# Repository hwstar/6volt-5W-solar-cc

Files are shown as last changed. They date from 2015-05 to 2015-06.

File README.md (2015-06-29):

***6volt-5W-solar-cc***
=============

This is a solar charge controller for use with 5 watt 6 volt solar panels.

**Introduction**

The project use a custom printed circuit board for the charge controller
power management electronics, and requires an external Arduino pro mini
to run the control firmware.

Setup in the lab:

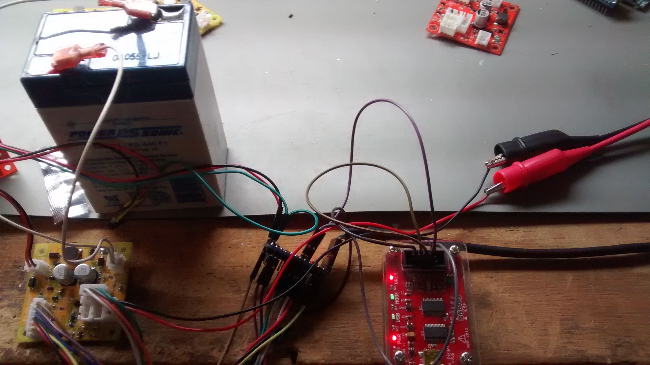
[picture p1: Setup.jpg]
ProjectSetup


The power management board design has the following features:

* PV input transient and reverse polarity protection
* Sensing for PV input voltage, converter output current, load current,
and battery voltage.
* PV Back feed protection using a dedicated MOSFET.
* PTC and reverse polarity protection on the battery connector.
* 3 sets of 3 pin connectors for loads. 
* 4 pin sense connector for current and voltage sensing to the Arduino
* 6 pin control connector for control signals from the Arduino
* Dedicated MOSFET for load switching.
* Switched and unswitched load configuration using solder jumpers.
* Double sided circuit board 5cm X 5cm

Front view of board:

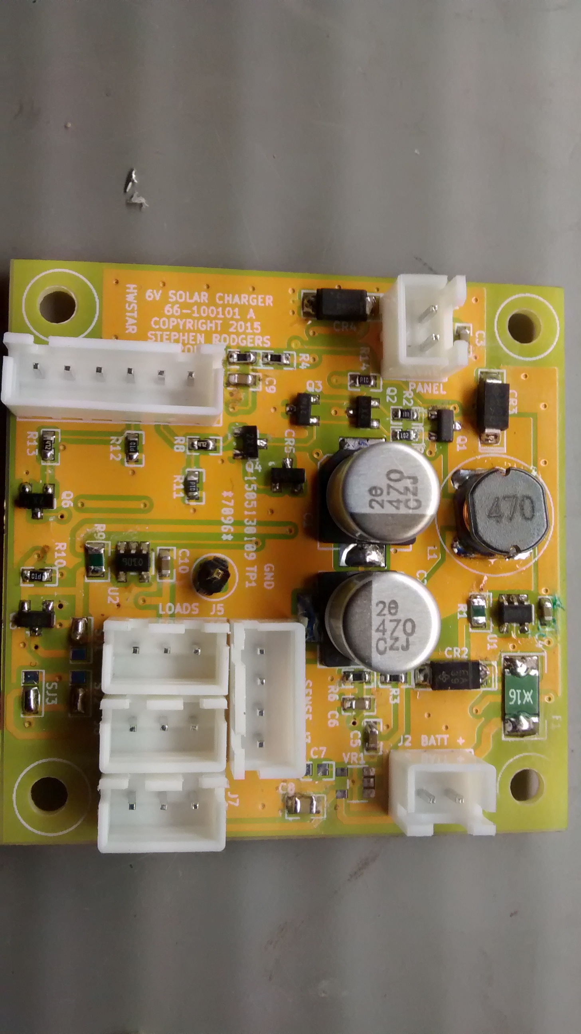
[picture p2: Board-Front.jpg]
BoardFront


Rear view of board:

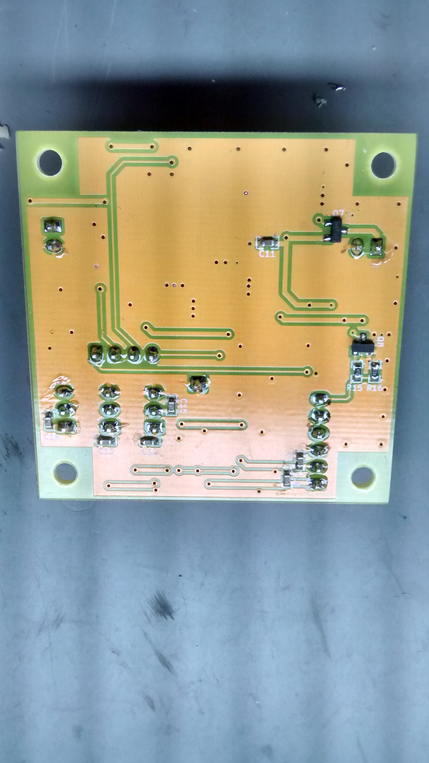
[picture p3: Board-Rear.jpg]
BoardRear


**Board Blanks**

Board blanks are available on Tindie:

https://www.tindie.com/products/hwstarsr/6-volt-5-watt-solar-charge-controller

**Firmware**

The firmware is hosted as a separate project on my github pages.
See [fw-6volt-5W-solar-cc](https://github.com/hwstar/fw-6volt-5W-solar-cc). For more details on
the firmware features, please visit the firmware page.

**Python/tkinter utility**

A Python/tkinter utility is available to download variables from the
charge controller in real time using a Bus Pirate and an I2C interface.
This is also hosted on my github pages under 
[chargectrlr-python-buspirate](https://github.com/hwstar/chargectrlr-python-buspirate).

**License**

CC-BY-SA

**Disclaimer**

This project uses a lead acid battery. Please observe all safety 
precautions listed on the battery. Enclose this project in a metallic
fireproof enclosure. Keep internal temperatures within the operating
limits of the battery. Not responsible for life, or loss of property
under any circumstance!

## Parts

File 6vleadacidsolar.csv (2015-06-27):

Item | Part Number | Qty | Reference(s) | Title/Description | Value on Schematic | Manufacturer | Manufacturer Part Number
1 | 800009-477 | 2 | C1,C2 | CAP,ELECT,8MM,470u,16V,LOW ESR | 470U | United Chemicon | EMZJ160ADA471MHA0G
2 | 800000-104 | 13 | C3-C6,C9-C15,C17,C18 | CAP,0603,0.1u,25V,X7R | 0.1U | Open Market | N/A
3 | 800002-471 | 1 | C7 | CAP,0603,470p,50V,C0G | 470p | Open Market | N/A
4 | 800003-106 | 1 | C8 | CAP,0805,10u,25V,X5R | 10U | Open Market | N/A
5 | 800109-101 | 2 | CR2,CR3 | DIODE, RECT,SHOTTKY,1A,50V,SMA | ES1A | Fairchild Semiconductor | ES1A
6 | 800132-013 | 1 | CR4 | DIODE,TVS,SMA,13V | 1SMA13AT3G | On Semiconductor | 1SMA13AT3G
7 | 800127-101 | 1 | CR5 | DIODE,SCHOTTKY,SGL,SOT-23 | BAT54 | Diodes Inc. | BAT54-7-F
8 | 800133-110 | 1 | F1 | FUSE,PTC,1812,1.1A,9V | 1.1A | Tyco Electronics | MINISMDC160F
9 | 800114-102 | 2 | J1,J2 | CONN,HDR,SHROUDED,2 CKT,5MM,XH SERIES | CONN2 | JST | B2B-XH-A
10 | 800114-104 | 1 | J3 | CONN,HDR,SHROUDED,4 CKT,5MM,XH SERIES | CONN4 | JST | B4B-XH-A
11 | 800114-106 | 1 | J4 | CONN,HDR,SHROUDED,6 CKT,5MM,XH SERIES | CONN6 | JST | B6B-XH-A
12 | 800114-103 | 3 | J5-J7 | CONN,HDR,SHROUDED,3 CKT,5MM,XH SERIES | CONN3 | JST | B3B-XH-A
13 | 800101-047 | 1 | L1 | IND,DRUM,UNSH,47UH,1.4A,SDE0805 SERIES | 47uH | Bourns | SDE0805A-470K
14 | 800134-101 | 3 | Q1,Q5,Q7 | XSTR,MOSFET,P-CH,SOT-23,30V,-7.6A | SI2369 | Vishay | SI2369DS-T1-E3
15 | 800110-101 | 4 | Q2,Q4,Q6,Q8 | XSTR,GP,NPN,40V,SOT23 | MMBT4401 | Fairchild Semiconductor | MMBT4401
16 | 800111-101 | 1 | Q3 | XSTR,GP,PNP,-40V,SOT23 | MMBT4403 | Fairchild Semiconductor | MMBT4403
17 | 800018-039 | 2 | R1,R9 | RES,0805,CUR SENSE,0.039 OHM,1%,1/2W | 0.039 | Susumu | KRL1220E-M-R039-F-T5
18 | 800010-104 | 5 | R10-R12,R14,R16 | RES,0603,100K OHM,5% | 100K | Open Market | N/A
19 | 800010-472 | 3 | R8,R13,R15 | RES,0603,4.7K OHM,5% | 4.7K | Open Market | N/A
20 | 800010-100 | 1 | R2 | RES,0603,10 OHM,5% | 10 | Open Market | N/A
21 | 800023-100 | 3 | R3,R6,R7 | RES,0603,10.0K OHM,1% | 10.0K | Open Market | N/A
22 | 800023-200 | 1 | R4 | RES,0603,20.0K OHM,1% | 20.0K | Open Market | N/A
23 | 800010-102 | 1 | R5 | RES,0603,1K OHM,5% | 1K | Open Market | N/A
24 | N/A | 3 | SJ1-SJ3 | Solder Jumper | GS3 | N/A | N/A
25 | 800122-101 | 2 | U1,U2 | IC,CURRENT SENSOR,100V/V,SOT23-5 | CS30CL | ST Microelectronics | CS30CL
26 | 800105-101 | 1 | VR1 | IC,VREG,5V,150MA,SOT23-5 | MIC5205 | Micrel | MIC5205YM5 TR

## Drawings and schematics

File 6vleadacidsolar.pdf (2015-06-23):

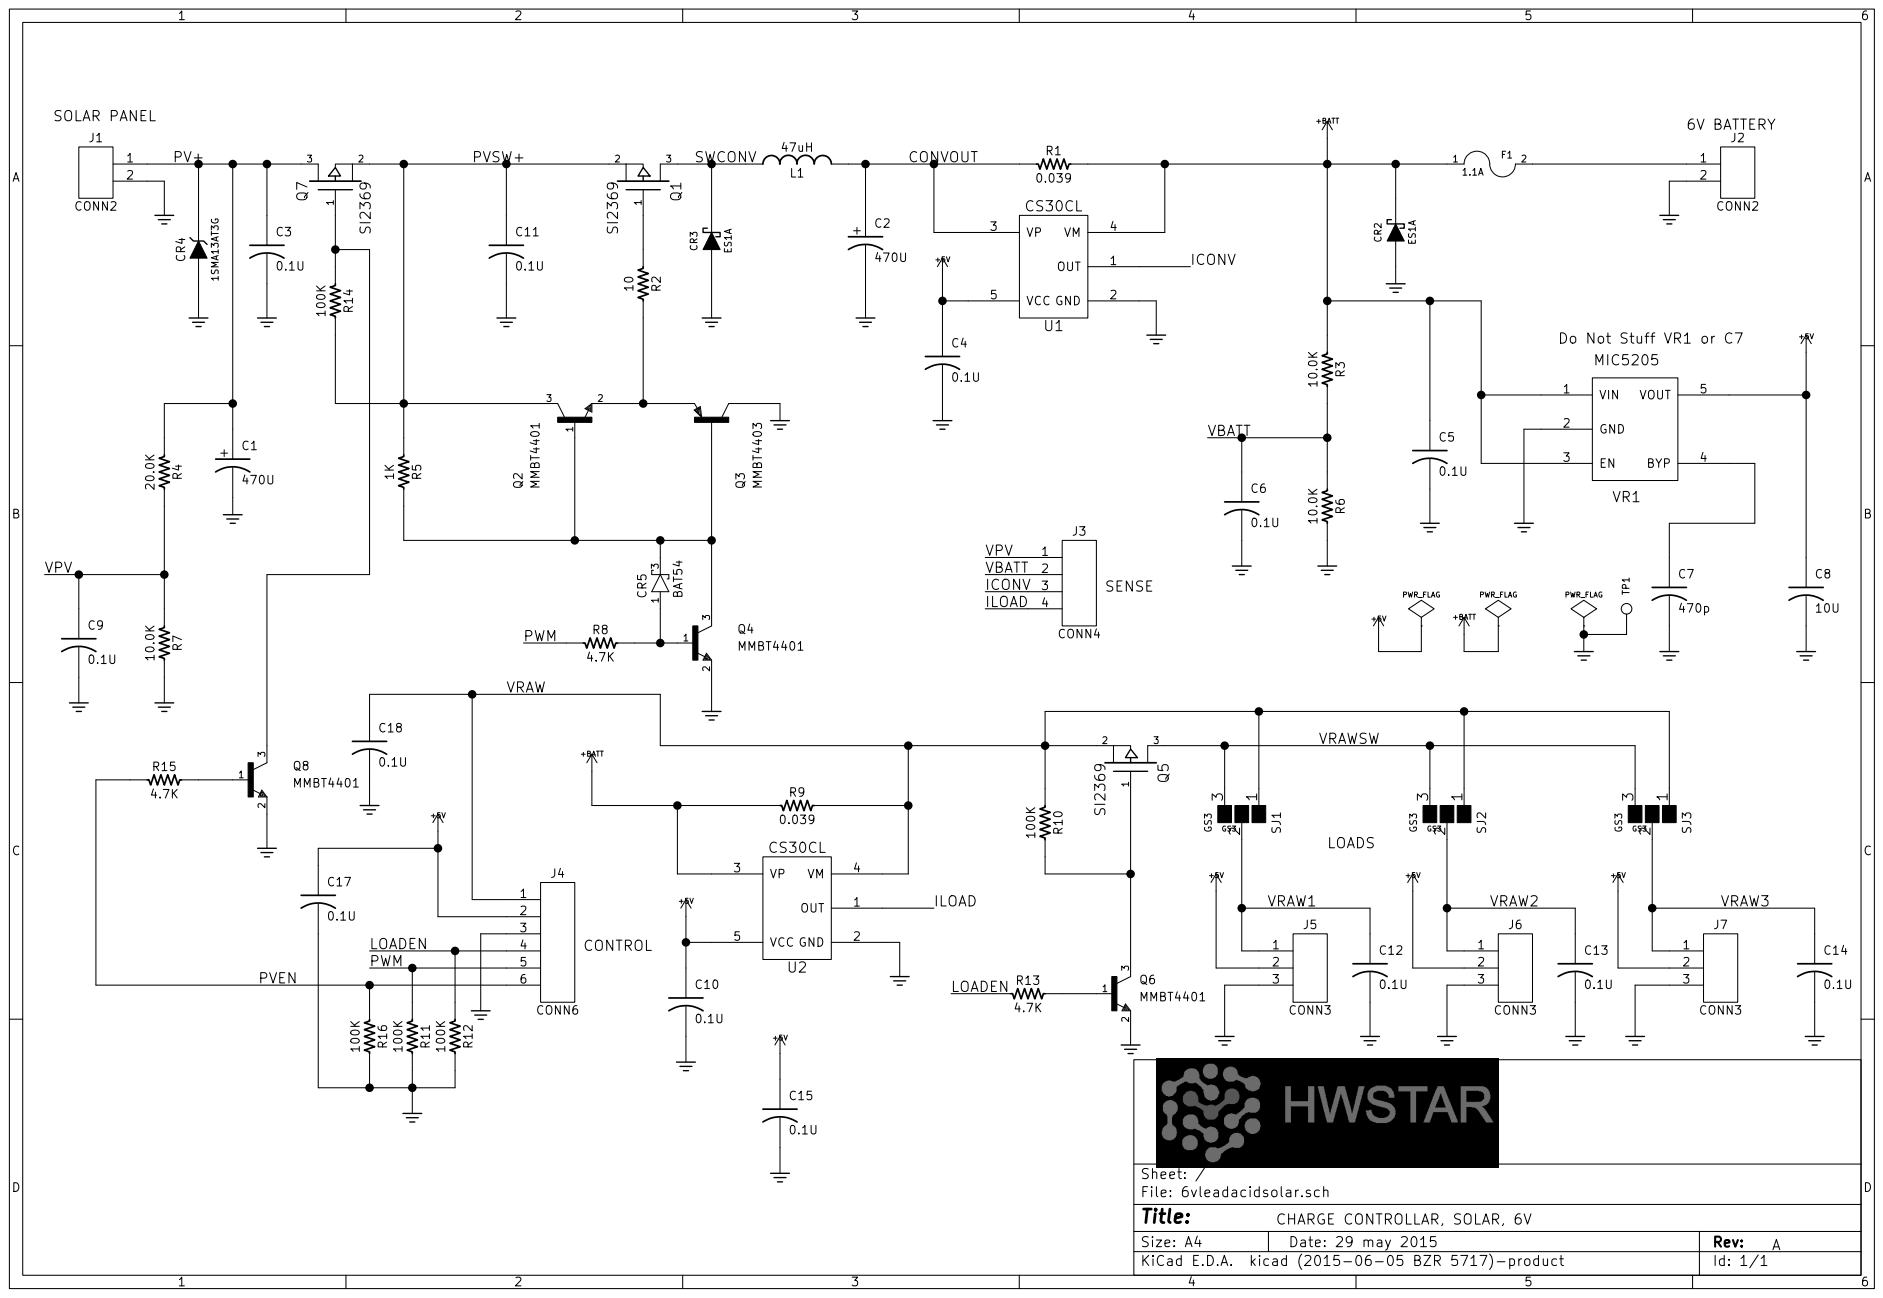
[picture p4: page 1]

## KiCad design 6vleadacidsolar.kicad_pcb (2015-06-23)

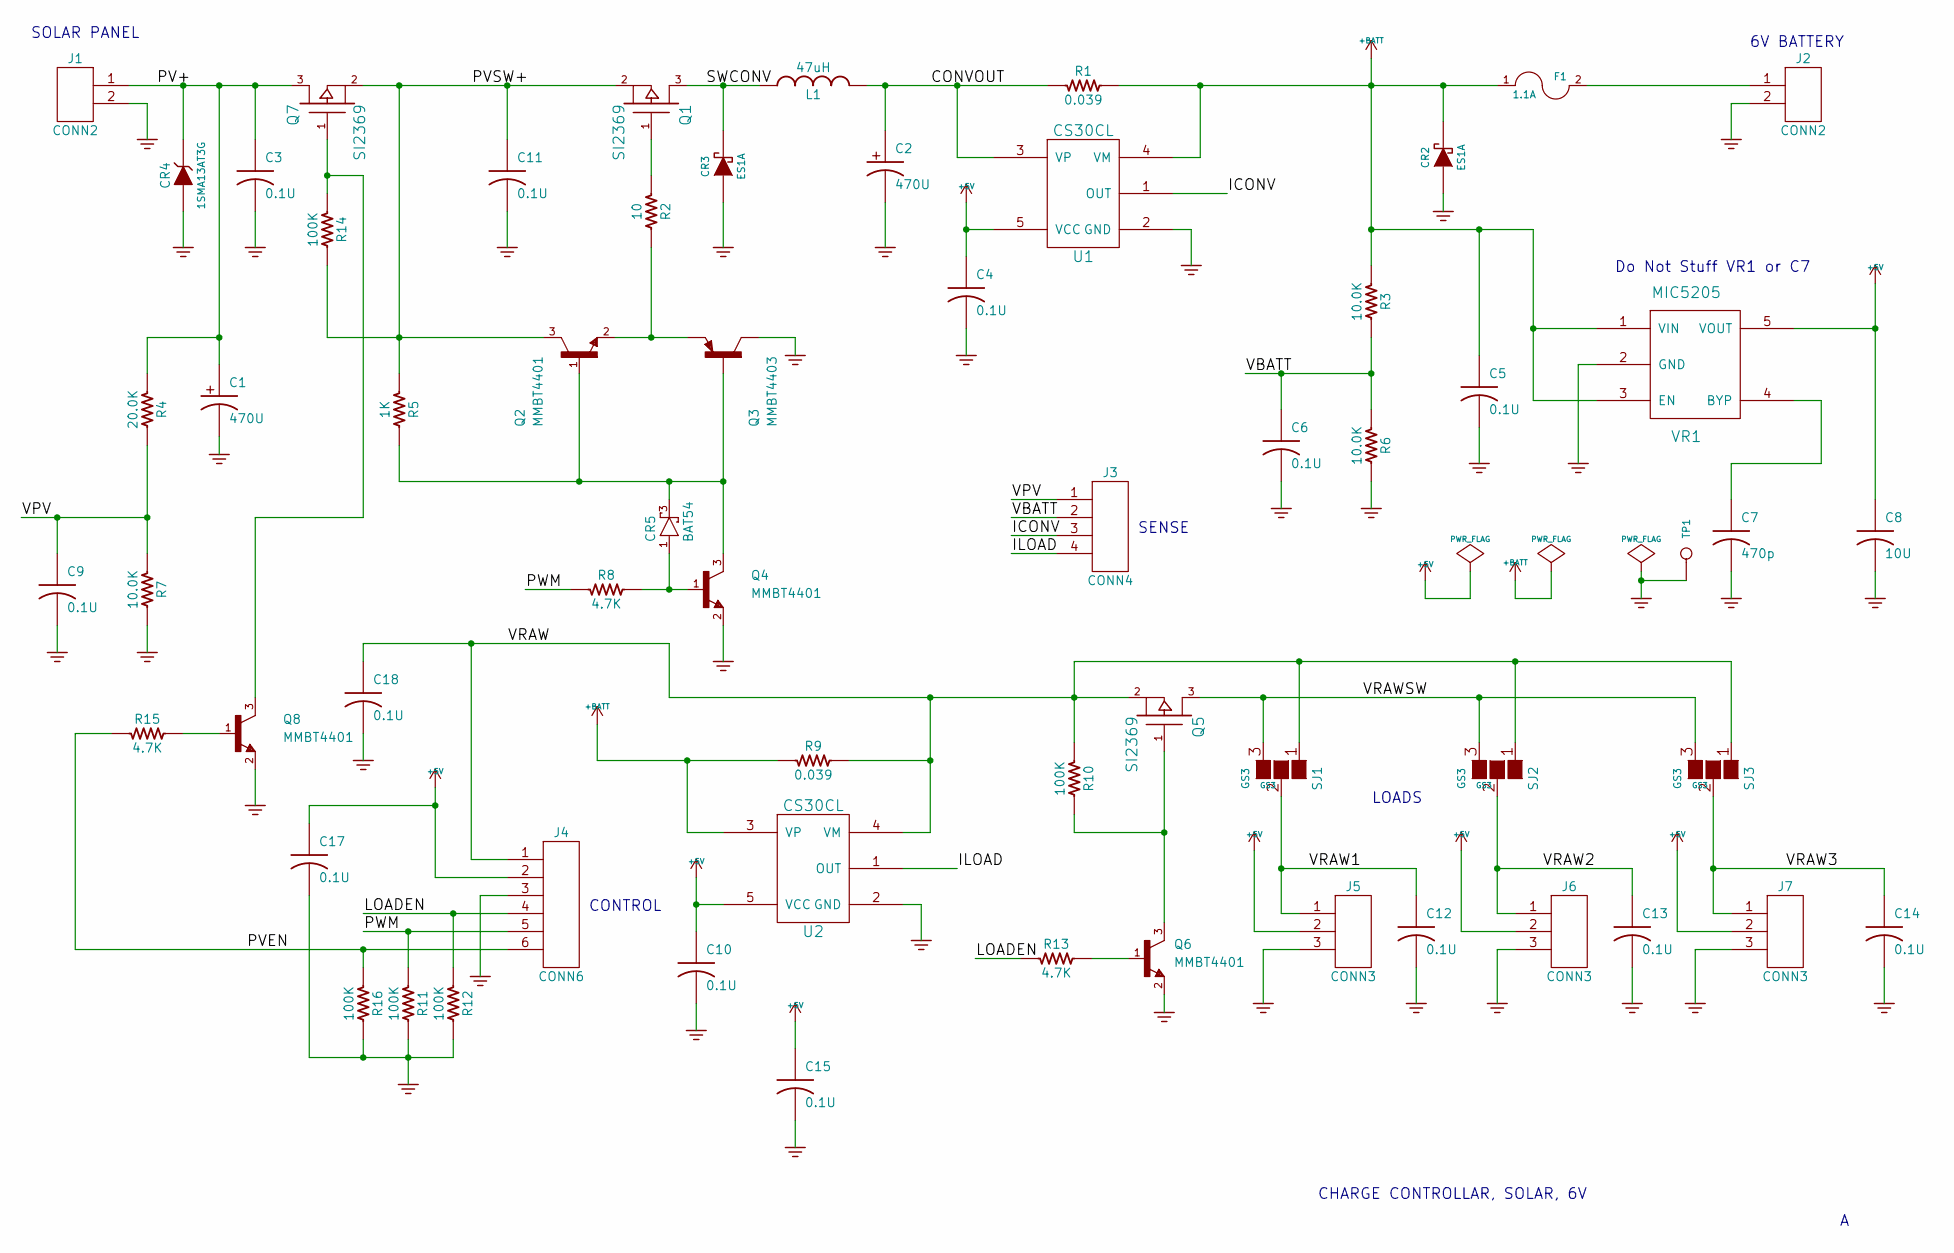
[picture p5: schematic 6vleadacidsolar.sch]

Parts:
C1, C2: 470U; PartNumber 800009-477
C3, C5, C6, C9, C10, C11, C12, C13, C14, C15, C17, C18: 0.1U; PartNumber 800000-104
C4: 0.1U
C7: 470p; PartNumber 800002-471
C8: 10U; PartNumber 800003-106
CR2, CR3: ES1A; PartNumber 800109-101
CR4: 1SMA13AT3G; PartNumber 800132-013
CR5: BAT54; SOT23; PartNumber 800127-101
F1: 1.1A; PartNumber 800133-110
J1, J2: CONN2; PartNumber 800114-102
J3: CONN4; PartNumber 800114-104
J4: CONN6; PartNumber 800114-106
J5, J6, J7: CONN3; PartNumber 800114-103
L1: 47uH; PartNumber 800101-047
Q1, Q5, Q7: SI2369; PartNumber 800134-101
Q2, Q4, Q6, Q8: MMBT4401; SOT23; PartNumber 800110-101
Q3: MMBT4403; custom-SOT23; PartNumber 800111-101
R1, R9: 0.039; PartNumber 800018-039
R2: 10; PartNumber 800010-100
R3, R6, R7: 10.0K; PartNumber 800023-100
R4: 20.0K; PartNumber 800023-200
R5: 1K; PartNumber 800010-102
R8, R13, R15: 4.7K; PartNumber 800010-472
R10, R11, R12, R14, R16: 100K; PartNumber 800010-104
SJ1, SJ2, SJ3: GS3
TP1: CONN_1
U1, U2: CS30CL; PartNumber 800122-101
VR1: MIC5205; SOT23-5; PartNumber 800105-101

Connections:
+5V: C4.1, C8.1, C10.1, C15.1, C17.1, J4.2, J5.2, J6.2, J7.2, U1.5 (VCC), U2.5 (VCC), VR1.5 (VOUT)
+BATT: C5.1, CR2.2 (K), F1.1, R1.2, R3.1, R9.1, U1.4 (VM), U2.3 (VP), VR1.1 (VIN), VR1.3 (EN)
/CONVOUT: C2.1, L1.2, R1.1, U1.3 (VP)
/ICONV: J3.3, U1.1 (OUT)
/ILOAD: J3.4, U2.1 (OUT)
/LOADEN: J4.4, R12.1, R13.1
/PV+: C1.1, C3.1, CR4.2 (K), J1.1, Q7.3 (D), R4.1
/PVEN: J4.6, R15.1, R16.1
/PVSW+: C11.1, Q1.2 (S), Q2.3 (C), Q7.2 (S), R5.1, R14.2
/PWM: J4.5, R8.1, R11.1
/SWCONV: CR3.2 (K), L1.1, Q1.3 (D)
/VBATT: C6.1, J3.2, R3.2, R6.1
/VPV: C9.1, J3.1, R4.2, R7.1
/VRAW: C18.1, J4.1, Q5.2 (S), R9.2, R10.1, SJ1.1 (G1), SJ2.1 (G1), SJ3.1 (G1), U2.4 (VM)
/VRAW1: C12.1, J5.1, SJ1.2 (G2)
/VRAW2: C13.1, J6.1, SJ2.2 (G2)
/VRAW3: C14.1, J7.1, SJ3.2 (G2)
/VRAWSW: Q5.3 (D), SJ1.3 (G3), SJ2.3 (G3), SJ3.3 (G3)
GND: C1.2, C2.2, C3.2, C4.2, C5.2, C6.2, C7.2, C8.2, C9.2, C10.2, C11.2, C12.2, C13.2, C14.2, C15.2, C17.2, C18.2, CR2.1 (A), CR3.1 (A), CR4.1 (A), J1.2, J2.2, J4.3, J5.3, J6.3, J7.3, Q3.3 (C), Q4.2 (E), Q6.2 (E), Q8.2 (E), R6.2, R7.2, R11.2, R12.2, R16.2, TP1.1, U1.2 (GND), U2.2 (GND), VR1.2 (GND)
unnamed: C7.1, VR1.4 (BYP)
unnamed: CR5.1 (A), Q4.1 (B), R8.2
unnamed: CR5.3 (C), Q2.1 (B), Q3.1 (B), Q4.3 (C), R5.2
unnamed: F1.2, J2.1
unnamed: Q1.1 (G), R2.1
unnamed: Q2.2 (E), Q3.2 (E), R2.2
unnamed: Q5.1 (G), Q6.3 (C), R10.2
unnamed: Q6.1 (B), R13.2
unnamed: Q7.1 (G), Q8.3 (C), R14.1
unnamed: Q8.1 (B), R15.2

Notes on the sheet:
6V BATTERY
SOLAR PANEL
CONTROL
SENSE
LOADS
CHARGE CONTROLLAR, SOLAR, 6V
Do Not Stuff VR1 or C7

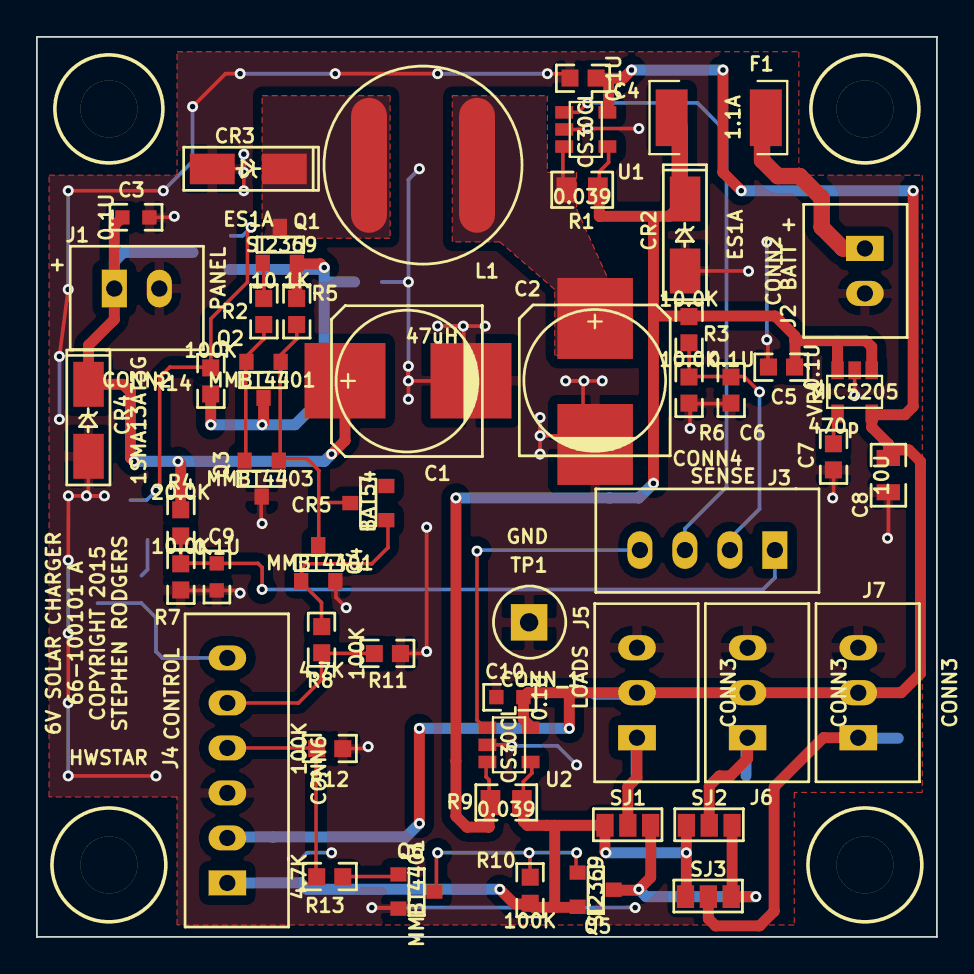
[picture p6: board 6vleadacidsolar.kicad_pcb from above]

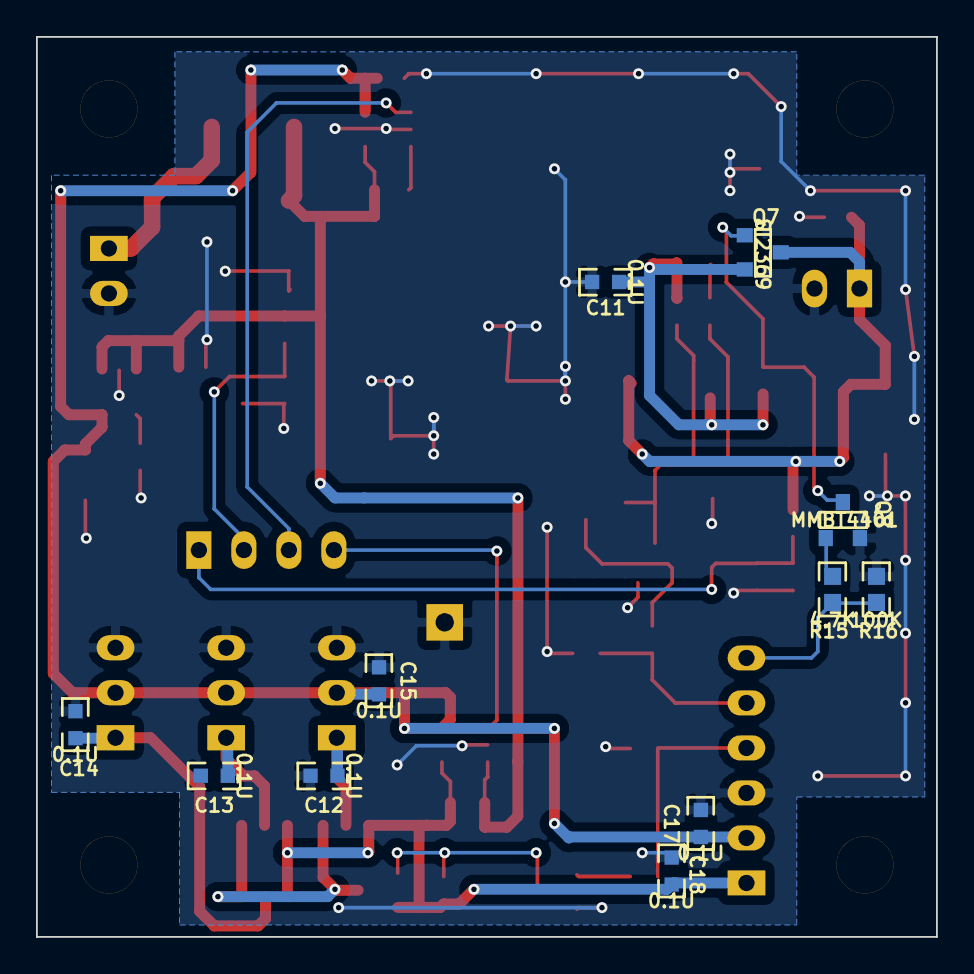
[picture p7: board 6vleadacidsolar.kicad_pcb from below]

Board: 2 copper layers, 50.0 x 50.0 mm, 65 parts (11 on the bottom side), 29 nets.

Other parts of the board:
MTGHOLE125, MTGHOLE125#2, MTGHOLE125#3, MTGHOLE125#4: VAL**; MTGHOLE125

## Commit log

2015-05-29 Initial Checkin
    [6vleadacidsolar-B_Cu.gbl, 6vleadacidsolar-B_Mask.gbs, 6vleadacidsolar-B_SilkS.gbo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]
2015-05-29 Fix typos
    [6vleadacidsolar.xlsx]
2015-06-22 Fix typo in BOM, update project file
    [6vleadacidsolar.xlsx]
2015-06-23 Schematic cleanup, add part numbers to parts in schematic
    [6vleadacidsolar.csv, 6vleadacidsolar.kicad_pcb, 6vleadacidsolar.sch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]
2015-06-27 Add missing letter to F1 MPN
    [6vleadacidsolar.csv]
2015-06-27 Correct solder jumper item
    [6vleadacidsolar.csv]

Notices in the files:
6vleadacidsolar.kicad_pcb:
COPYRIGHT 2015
